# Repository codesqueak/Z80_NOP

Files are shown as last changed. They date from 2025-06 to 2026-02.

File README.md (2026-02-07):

# Z80 NOP Tester v1.2 

Z80 CPU NOP Instruction Tester

## Introduction

This board has been designed to allow a Z80 to run NOP instructions slowly enough to see address and various control lines to aid in diagnostics

In Z80 assembly, NOP (No Operation) is the opcode 0x00.

When executed, the CPU does nothing for one machine cycle and then increments the program counter (PC) to fetch the next instruction.

## What it Tests
* Clock circuit (CPU is being driven)
* Reset circuit (PC starts at 0x0000)
* Address bus (sequential counting)
* Basic instruction fetch and decode mechanism

## What You Can See
* A display of the address bus contents as it increments
* Status of RFSH, M1, MREQ and RD signals

## What You Can Measure
* Test points for clock, 0V and 5V
* Test points for s RFSH, M1, MREQ, RD IORQ, WR, HALT, BUSACK (Useful if your Z80 is mis-behaving)

# Z80 NOP HALT Tester v2.1

Z80 CPU NOP HALT Instruction Tester

## Introduction

An extended version of the board which allows the use of HALT instructions to test dynamic memory refresh operations

In Z80 assembly, HALT is the opcode 0x76.

When executed, the CPU enters HALT mode and ceases executing except for memory refresh operations

## Documentation

For full documentation, see the [NOP pdf here](Z80_NOP.pdf) and [NOP HALT pdf here](Z80_NOP_HALT.pdf)

## Release 1.2 Boards

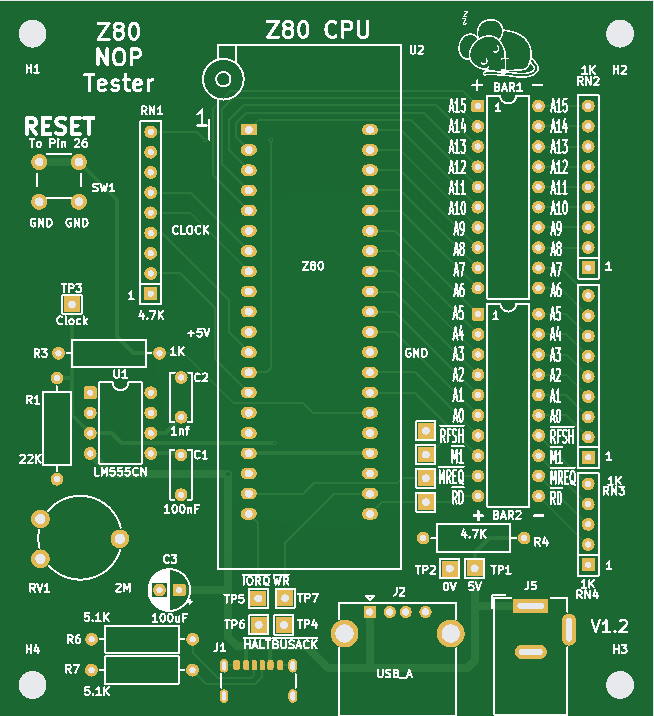
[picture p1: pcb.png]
PCB From JLCPCB


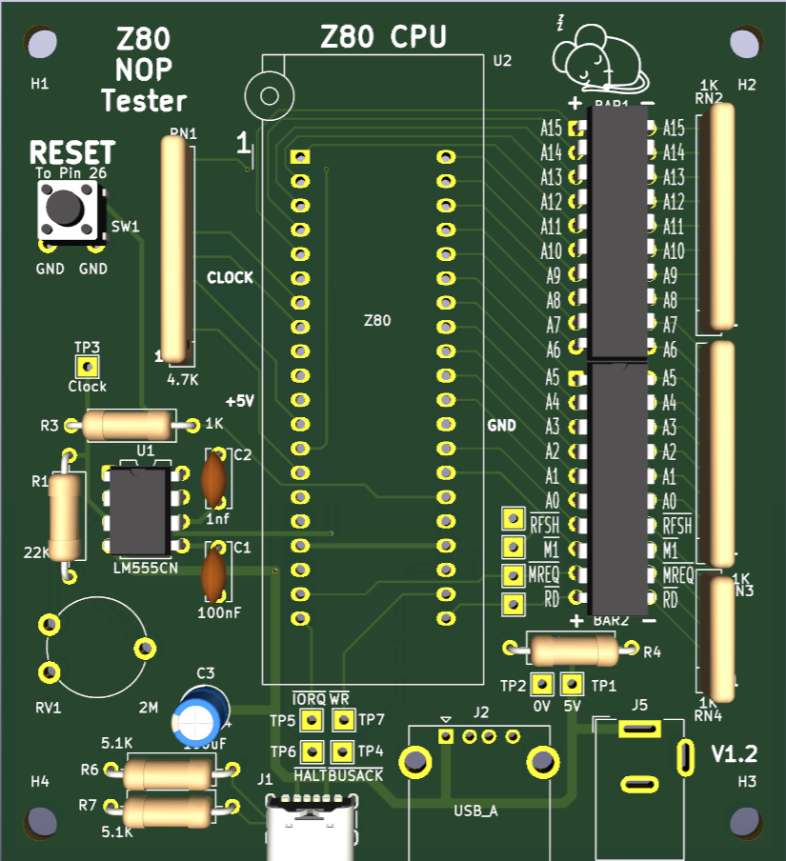
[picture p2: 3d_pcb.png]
Model


Built PCB

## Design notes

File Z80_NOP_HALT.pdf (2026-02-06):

Z80 NOP / HALT Instruction Tester

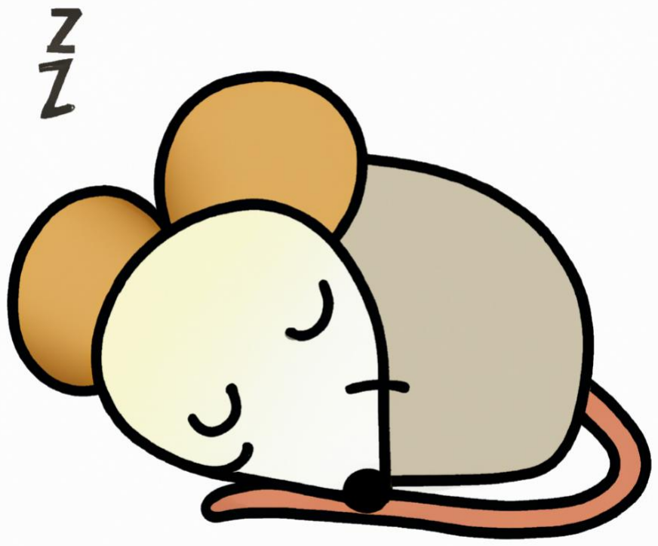
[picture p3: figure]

Issue 2.1 | Page 1 | 06-Feb-2026

## Z80 NOP / HALT Instruction Tester

Instruction Manual & Functional Description

Issue 2.1 | Page 2 | 06-Feb-2026

## Document History

Date | Reason
06_Feb-2026 | Original release

Issue 2.1 | Page 3 | 06-Feb-2026

## Contents

Issue 2.1 | Page 4 | 06-Feb-2026

## 1 Introduction

A Z80 NOP / HALT tester is a simple diagnostic tool used to check whether a Z80 microprocessor is basically functional — specifically, whether it can fetch and execute instructions from memory.

### 1.1 NOP Instruction

In Z80 assembly, NOP (No Operation) is the opcode 0x00.

When executed, the CPU does nothing for one machine cycle and then increments the program counter (PC) to fetch the next instruction.

### 1.2 HALT Instruction

In Z80 assembly, HALT is the opcode 0x76.

When executed, the CPU halts normal operation and can only be restarted by a reset, interrupt or power cycle. Despite execution halting, bus cycles to maintain memory refresh cycles continue. This is useful to check refresh operations are concurringly correctly.

### 1.3 The Tester’s Trick

The tester provides the Z80 with a "fake" memory where every address returns 0x00 (NOP) or 0x76 (HALT)

### 1.4 Expected Behavior - NOP

With only NOPs available, the Z80 should:

- Continuously fetch opcodes (all NOPs).
- Increment the PC from 0x0000 to 0xFFFF, then wrap around.
- Output the address on the address bus sequentially, one step per instruction cycle.

### 1.5 What it Tests

- Clock circuit (CPU is being driven).
- Reset circuit (PC starts at 0x0000).
- Address bus (sequential counting).
- Basic instruction fetch and decode mechanism.

### 1.6 What You Can See

- A display of the address bus contents as it increments
- Status of HALT, RFSH, M1 and MREQ signals

### 1.7 What You Can Measure

- Test points for clock, 0V and 5V
- Test points for s RFSH, M1, MREQ, RD IORQ, WR, HALT, BUSACK (Useful if your Z80 is mis-behaving)

### 1.8 Expected Behavior - HALT

With only HALTs available, the Z80 should:

- HALT LED goes blank (Active low)
- Cease incrementing the PC

Issue 2.1 | Page 5 | 06-Feb-2026
- Output the address on the address bus sequentially for refresh. only lower 7 bits (A0..A6). A7 to A15 should remain off in this mode

### 1.9 What it Tests

- Clock circuit (CPU is being driven).
- Reset circuit (CPU enters HALT mode).
- Address bus (sequential counting for refresh only).
- Basic instruction fetch and decode mechanism.

### 1.10 What You Can See

- A display of the address bus contents as it increments
- Status of HALT, RFSH, M1 and MREQ signals

### 1.11 What You Can Measure

- Test points for clock, 0V and 5V
- Test points for s RFSH, M1, MREQ, RD IORQ, WR, HALT, BUSACK (Useful if your Z80 is mis-behaving)

With this it is possible to confirm basic IC functionality while looking at expected signal quality (if you have a scope to hand)

Issue 2.1 | Page 6 | 06-Feb-2026

## 2 Components

Reference | Value | Qty | Part
BAR1 | LED_Bar_10 | 1 | OSX10201-G
BAR2 | LED_Bar_10 | 1 | OSX10201-RGG
C1 | 100nF | 1 | Ceramic
C2 | 1nf | 1 | Ceramic (*)
C3 | 100uF | 1 | Electrolytic
C4 | 10nF | 1 | Ceramic
J1 | USB_C_Receptacle_PowerOnly_6P | 1 | USB4125-GF-A
J2 | USB_A | 1 | KUSBX-AS1N
J5 | Barrel Jack | 1 | Wurth 694108301002
R1 | 22K | 1
R3 | 1K | 1
R4 | 4.7K | 1
R6, R7 | 5.1K | 2 | Optional on J1 being fitted
RN1 | 4.7K | 1 | 4116R-1-472
RN2, RN3 | 1K | 2 | 4609M-101-102LF
RN4 | 1K | 1 | 4605X-101-102LF
RV1 | 2M | 1 | PT10LV10-205A2020-S
SW1 | Switch Push | 1
SW1 | Switch Slide | 1
TP1 | 5V | 1
TP2 | 0V | 1
TP3 | Clock | 1
TP4 | BUSACK | 1
TP5 | IORQ | 1
TP6 | RD | 1
TP7 | WR | 1
TP8 | HALT | 1
TP9 | MREQ | 1
TP10 | M1 | 1
TP11 | RFSH | 1
U1 | 555 Timer | 1 | LM555CN
U2 | Z80 | 1 | Test Item

(*) Can be changed to give a different clock range. See section 5

Issue 2.1 | Page 7 | 06-Feb-2026

## 3 Construction

### 3.1 Before you start construction

Inspect the PCB for any visible signs of damage

Select your components:

- Turned pin sockets are recommended due to robustness and reliability

### 3.2 Order of construction

The recommended order of construction is:

- Resistors
- Sockets
- Resistor packs
- LED’s
- Power connectors
- Reset switch
- ZIF Socket
- Insert IC

### 3.3 Note on USB C

If the USB C connector is not to be fitted then the two 5.1K resistors (R6 & R7) are also not required.

Issue 2.1 | Page 8 | 06-Feb-2026

## 4 Functionality

### 4.1 Order of Operation

To test a CPU, the following steps are required

- Put the CPU in the ZIF socket and clamp it
- Select either NOP or HALT mode
- Apply power via one of the power inputs
- Press the reset button

### 4.2 Operation Speed

Depending on the clock speed selected A0 may appear fully lit or flicker due to the rate of change

The time taken / speed of operation is controlled by the variable resistor RV1. In standard configuration this gives an approximate clock of between 325Hz and 22KHz

It is possible to change C1 and C2 to give other ranges if required. For example, using C1 @ 47nF and C2 at 2.2nF gives an approximate clock of between 150Hz and 10KHz

The original C1, C2 values have been chosen to give reasonable time performance while making the address bus changes visible.

### 4.3 Expected Output - NOP

The LED’s representing A0 through A15 should now count in the sequence as the CPU runs through addresses 0000 to FFFF

The four LED’s representing HALT, RFSH, M1 and MREQ should all stay lit. RFSH, M1 and MREQ do change state but too quickly to be easily visible. Using a scope on their test points if recommended if exact operation needs to be observed.

### 4.4 Expected Output - HALT

The LED’s representing A0 through A6 should now count in the sequence as the CPU runs through its refresh address generation. A7 through A15 should not light.

The three LED’s representing RFSH, M1 and MREQ should all stay lit. They do change state but too quickly to be easily visible. Using a scope on their test points if recommended if exact operation needs to be observed.

The HALT LED should not be lit. This indices the CPU is in HALT mode

Issue 2.1 | Page 9 | 06-Feb-2026

Issue 2.1 | Page 10 | 06-Feb-2026

## 5 Notes on Components

All the components used have been selected at time of design to be readily available via eBay and other sources.

All components with the exception of the USB C connector are through hole so specialist tooling is not required

It is recommended that all through hole resistors are rated at 0.5W for over-rating reliability

The ZIF socket can be soldered directly to the board. You may wish to consider using a socket to mount the ZIF socket into as they can be expensive and easy to damage via soldering.

Make sure the reset button is oriented correctly before soldering

Not all 555’s seem to be created equal. I strongly recommend using an LM555CN

Th e capacitor at C2 is set to 1nF. This gives a range of approximately 325Hz to 22KHz. This may be changes as follows:

Capacitor | Approx Min | Approx Max
1nF | 325Hz | 22KHz
2.2nF | 150Hz | 10KHz
4.7nF | 75Hz | 5KHz

Issue 2.1 | Page 11 | 06-Feb-2026

## 6 Errata

None so far …

Issue 2.1 | Page 12 | 06-Feb-2026

## 7 Design Files

https://github.com/codesqueak/Z80_NOP

Issue 2.1 | Page 13 | 06-Feb-2026

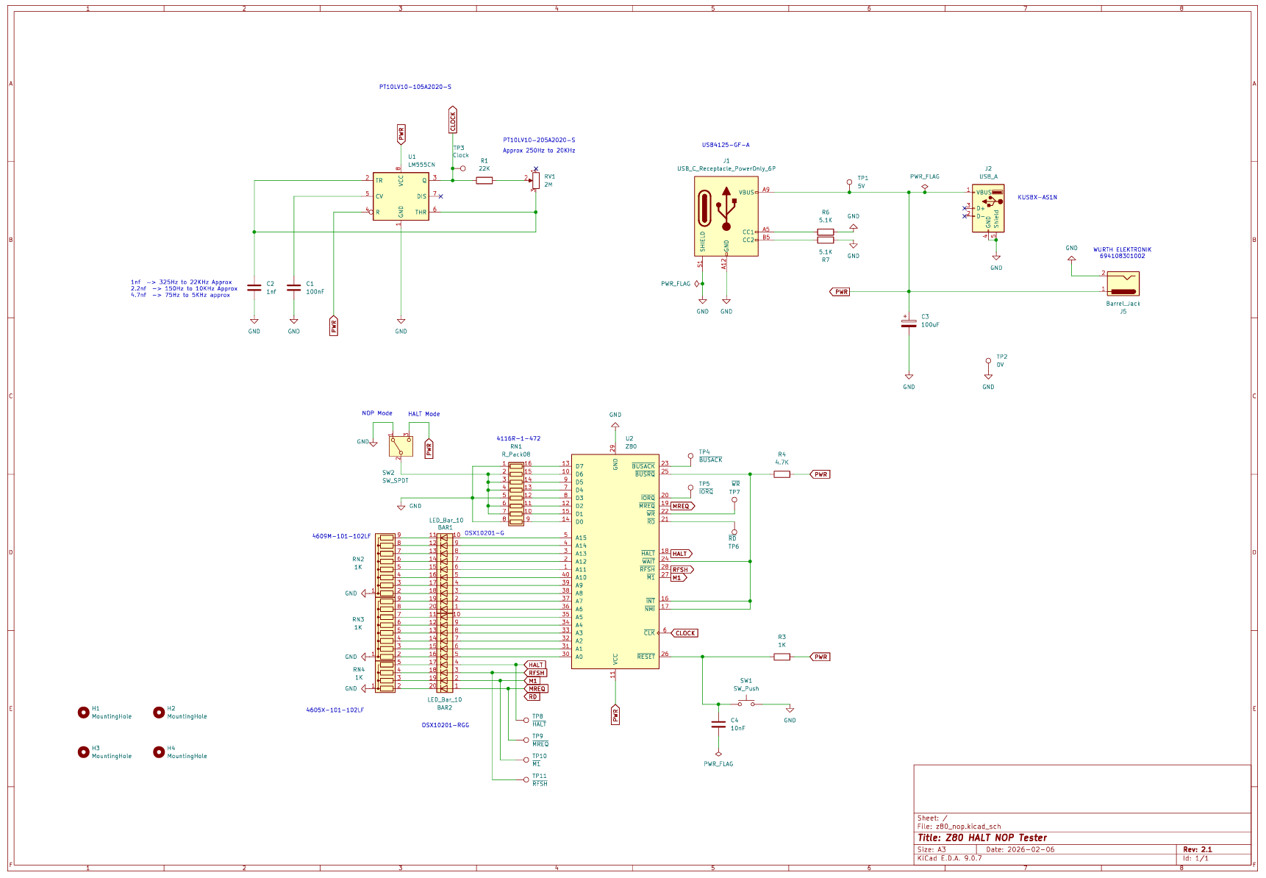
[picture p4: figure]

Issue 2.1 | Page 14 | 06-Feb-2026

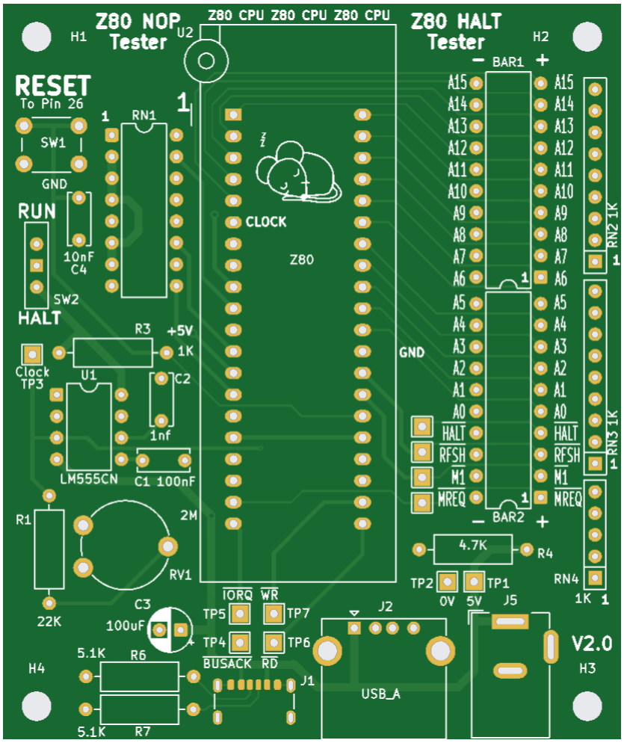
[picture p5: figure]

Issue 2.1 | Page 15 | 06-Feb-2026

## 8 Reference Images

### 8.1 PCB

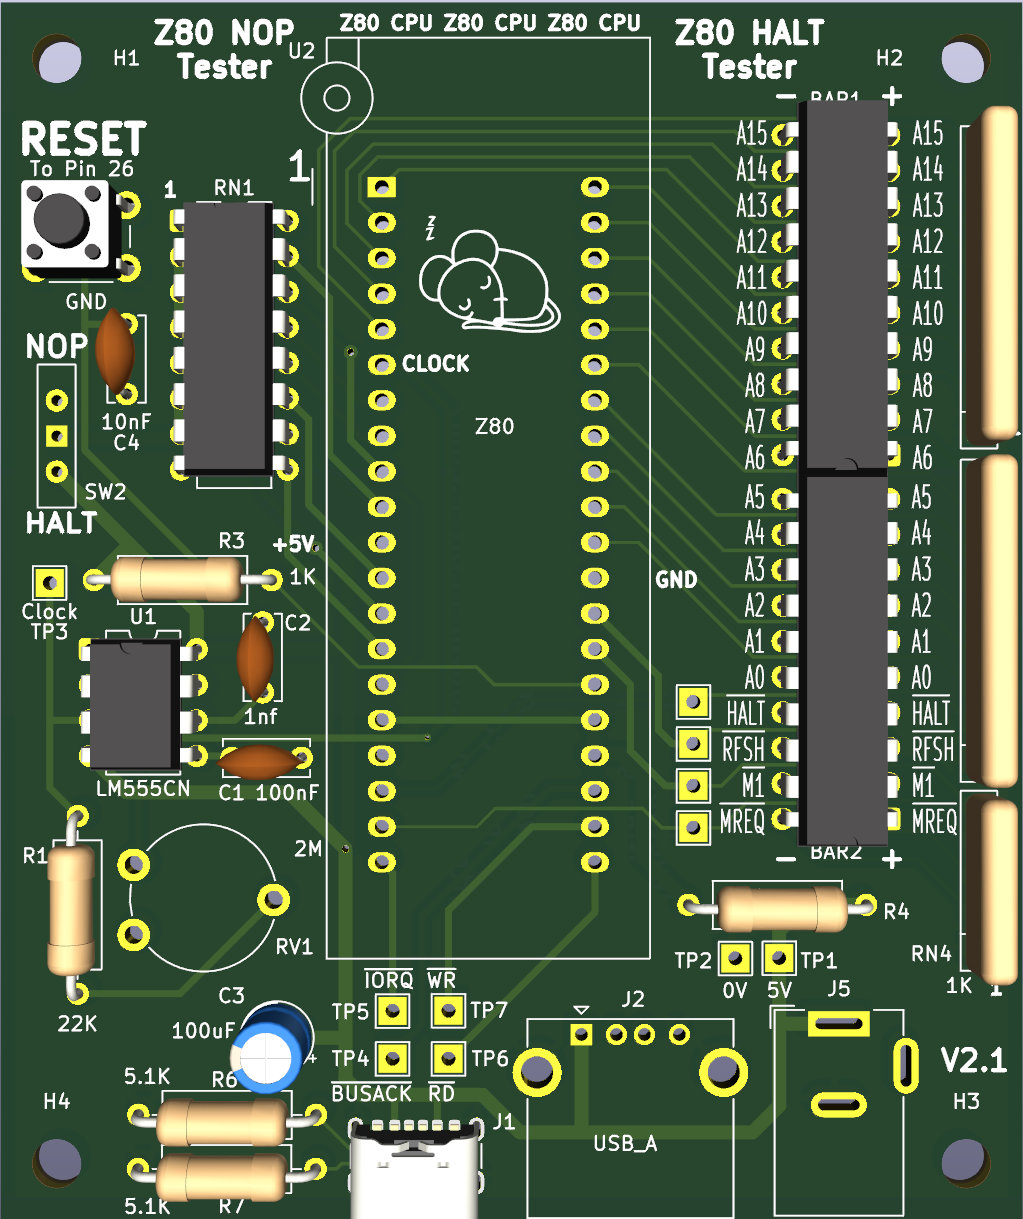
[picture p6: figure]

Issue 2.1 | Page 16 | 06-Feb-2026

### 8.2 Built

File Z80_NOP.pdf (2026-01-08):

Z80 NOP Instruction Tester


Issue 1.3 | Page 1 | 08-Jan-2026

## Z80 NOP Instruction Tester

Instruction Manual & Functional Description

Issue 1.3 | Page 2 | 08-Jan-2026

## Document History

Date | Reason
11-Aug-2025 | Original release
04-Oct-2025 | Minor corrections
08-Jan-2026 | Additional capacitor to clock speed selections

Issue 1.3 | Page 3 | 08-Jan-2026

## Contents

Issue 1.3 | Page 4 | 08-Jan-2026

## 1 Introduction

A Z80 NOP tester is a simple diagnostic tool used to check whether a Z80 microprocessor is basically functional — specifically, whether it can fetch and execute instructions from memory.

### 1.1 NOP Instruction

In Z80 assembly, NOP (No Operation) is the opcode 0x00.

When executed, the CPU does nothing for one machine cycle and then increments the program counter (PC) to fetch the next instruction.

### 1.2 The Tester’s Trick

The tester provides the Z80 with a "fake" memory where every address returns 0x00 (NOP).

### 1.3 Expected Behavior

With only NOPs available, the Z80 should:

- Continuously fetch opcodes (all NOPs).
- Increment the PC from 0x0000 to 0xFFFF, then wrap around.
- Output the address on the address bus sequentially, one step per instruction cycle.

### 1.4 What it Tests

- Clock circuit (CPU is being driven).
- Reset circuit (PC starts at 0x0000).
- Address bus (sequential counting).
- Basic instruction fetch and decode mechanism.

### 1.5 What You Can See

- A display of the address bus contents as it increments
- Status of RFSH, M1, MREQ and RD signals

### 1.6 What You Can Measure

- Test points for clock, 0V and 5V
- Test points for s RFSH, M1, MREQ, RD IORQ, WR, HALT, BUSACK (Useful if your Z80 is mis-behaving)

With this it is possible to confirm basic IC functionality while looking at expected signal quality (if you have a scope to hand)

Issue 1.3 | Page 5 | 08-Jan-2026

## 2 Components

Reference | Value | Qty | Part
BAR1,BAR2 | LED_Bar_10 | 2 | OSX10201-G
C1 | 100nF | 1 | Ceramic
C2 | 1nf | 1 | Ceramic (*)
C3 | 100uF | 1 | Electrolytic
J1 | USB_C_Receptacle_PowerOnly_6P | 1 | USB4125-GF-A
J2 | USB_A | 1 | KUSBX-AS1N
J5 | Barrel Jack | 1 | Wurth 694108301002
R1 | 22K | 1
R3 | 1K | 1
R4 | 4.7K | 1
R6, R7 | 5.1K | 2 | Optional on J1 being fitted
RN1 | 4.7K | 1 | 4609M-101-472LF
RN2, RN3 | 1K | 2 | 4609M-101-102LF
RN4 | 1K | 1 | 4605X-101-102LF
RV1 | 2M | 1 | PT10LV10-205A2020-S
SW1 | Switch Push | 1 | D6L90 F2 LFS
TP1 | 5V | 1
TP2 | 0V | 1
TP3 | Clock | 1
TP4 | BUSACK | 1
TP5 | IORQ | 1
TP6 | HALT | 1
TP7 | WR | 1
TP8 | RD | 1
TP9 | MREQ | 1
TP10 | M1 | 1
TP11 | RFSH | 1
U1 | 555 Timer | 1 | LM555CN
U2 | Z80 | 1 | Test Item

(*) Can be changed to give a different clock range. See section 5

Issue 1.3 | Page 6 | 08-Jan-2026

## 3 Construction

### 3.1 Before you start construction

Inspect the PCB for any visible signs of damage

Select your components:

- Turned pin sockets are recommended due to robustness and reliability

### 3.2 Order of construction

The recommended order of construction is:

- Resistors
- Sockets
- Resistor packs
- LED’s
- Power connectors
- Reset switch
- ZIF Socket
- Insert IC

### 3.3 Note on USB C

If the USB C connector is not to be fitted then the two 5.1K resistors (R6 & R7) are also not required.

Issue 1.3 | Page 7 | 08-Jan-2026

## 4 Functionality

### 4.1 Order of Operation

To test a CPU, the following steps are required

- Put the CPU in the ZIF socket and clamp it
- Apply power via one of the power inputs
- Press the reset button

### 4.2 Expected Output

The LED’s representing A0 through A15 should now count in the sequence as the CPU runs through addresses 0000 to FFFF

Depending on the clock speed selected A0 may appear fully lit or flicker due to the rate of change

The time taken / speed of operation is controlled by the variable resistor RV1. In standard configuration this gives an approximate clock of between 325Hz and 22KHz

It is possible to change C1 and C2 to give other ranges if required. For example, using C1 @ 47nF and C2 at 2.2nF gives an approximate clock of between 150Hz and 10KHz

The original C1, C2 values have been chosen to give reasonable time performance while making the address bus changes visible.

The four LED’s representing RFSH, M1, MREQ and RD should all stay lit. They do change state but too quickly to be easily visible. Using a scope on their test points if recommended if exact operation needs to be observed.

Issue 1.3 | Page 8 | 08-Jan-2026

## 5 Notes on Components

All the components used have been selected at time of design to be readily available via eBay and other sources.

All components with the exception of the USB C connector are through hole so specialist tooling is not required

It is recommended that all through hole resistors are rated at 0.5W for over-rating reliability

The ZIF socket can be soldered directly to the board. You may wish to consider using a socket to mount the ZIF socket into as they can be expensive and easy to damage via soldering.

Make sure the reset button is oriented correctly before soldering

Not all 555’s seem to be created equal. I strongly recommend using an LM555CN

Th e capacitor at C2 is set to 1nF. This gives a range of approximately 325Hz to 22KHz. This may be changes as follows:

Capacitor | Approx Min | Approx Max
1nF | 325Hz | 22KHz
2.2nF | 150Hz | 10KHz
4.7nF | 75Hz | 5KHz

Issue 1.3 | Page 9 | 08-Jan-2026

## 6 Errata

None so far …

Issue 1.3 | Page 10 | 08-Jan-2026

## 7 Design Files

https://github.com/codesqueak/Z80_NOP

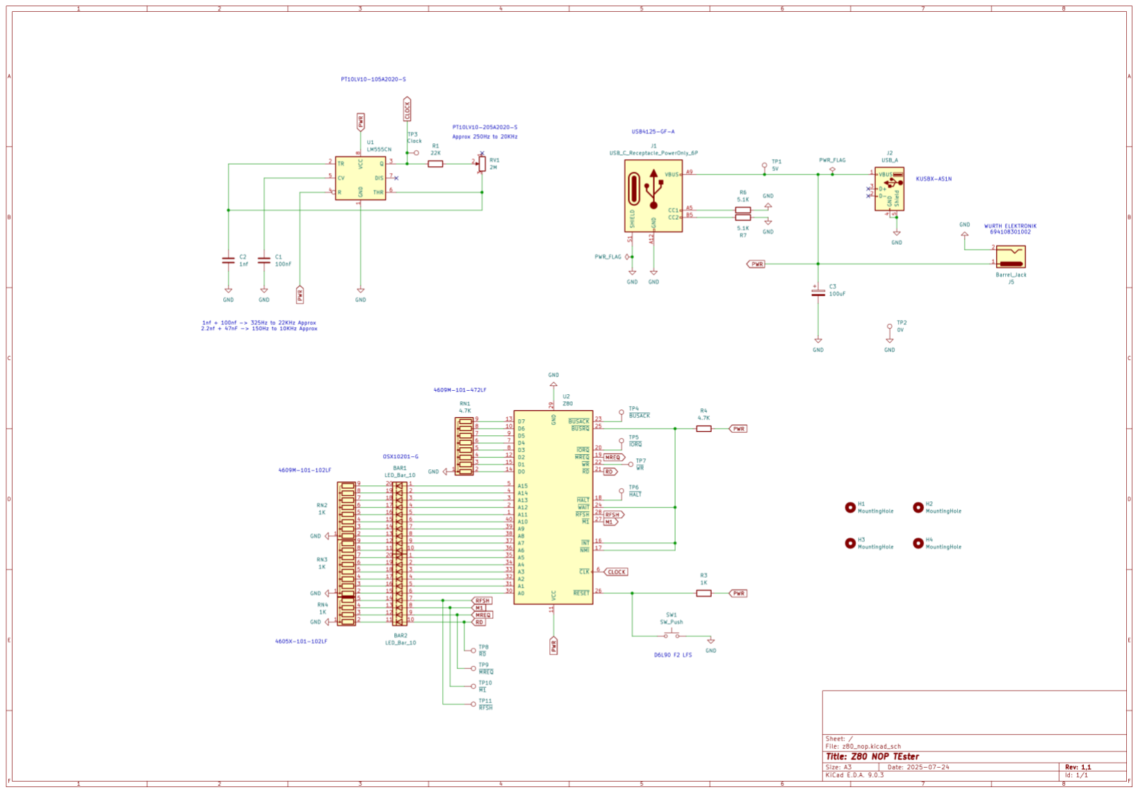
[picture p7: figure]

Issue 1.3 | Page 11 | 08-Jan-2026

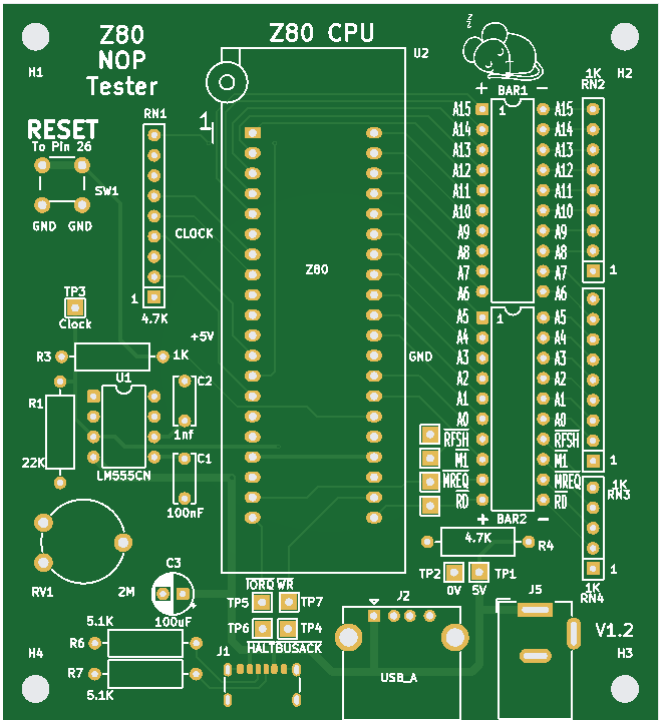
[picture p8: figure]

Issue 1.3 | Page 12 | 08-Jan-2026

## 8 Reference Images

### 8.1 PCB

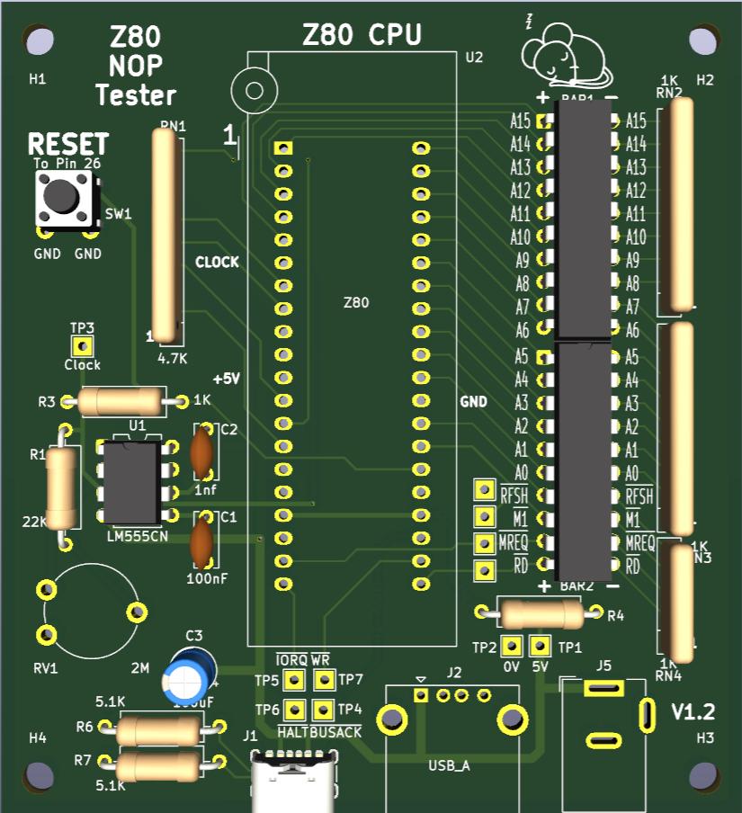
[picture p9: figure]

Issue 1.3 | Page 13 | 08-Jan-2026

### 8.2 Built

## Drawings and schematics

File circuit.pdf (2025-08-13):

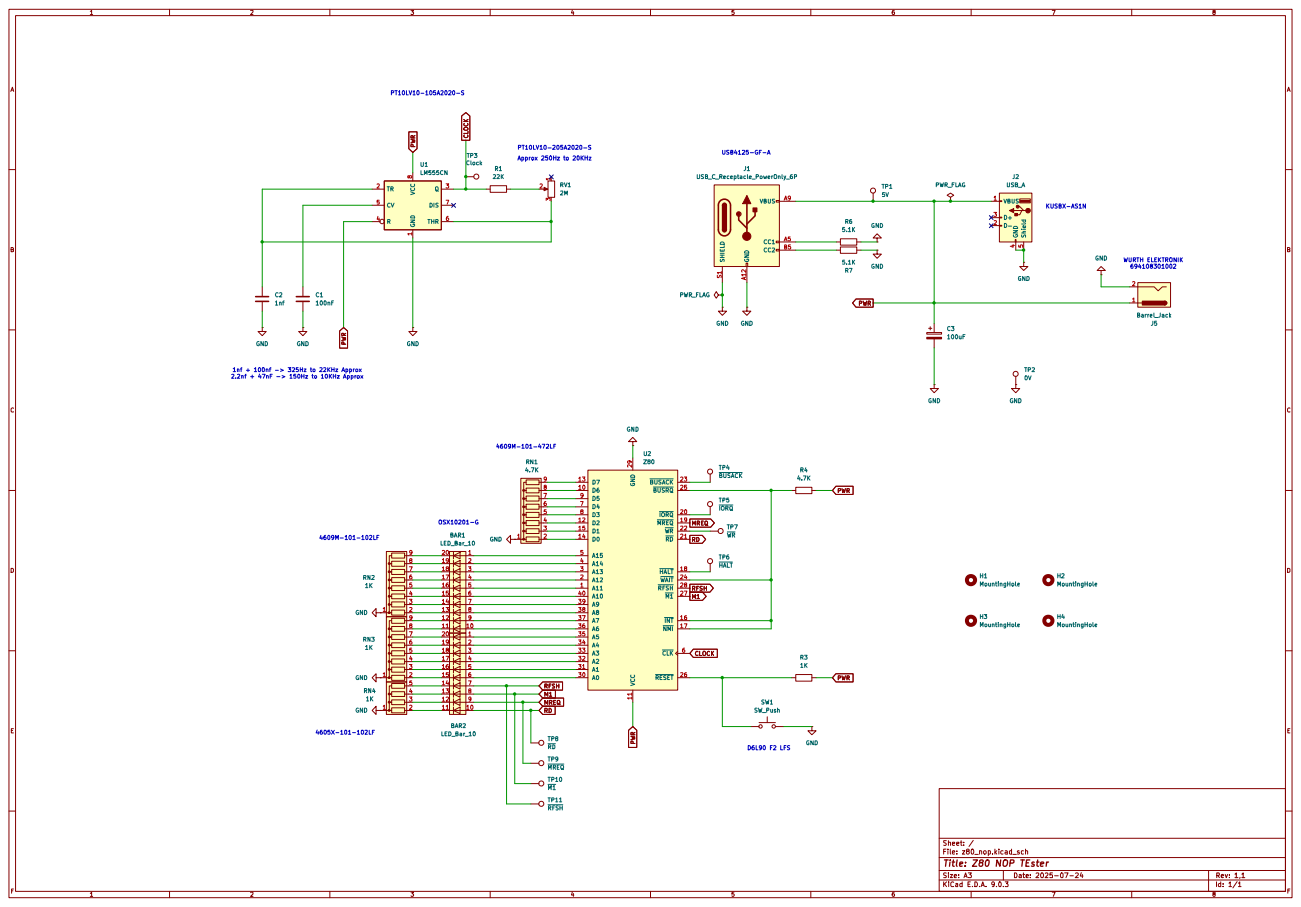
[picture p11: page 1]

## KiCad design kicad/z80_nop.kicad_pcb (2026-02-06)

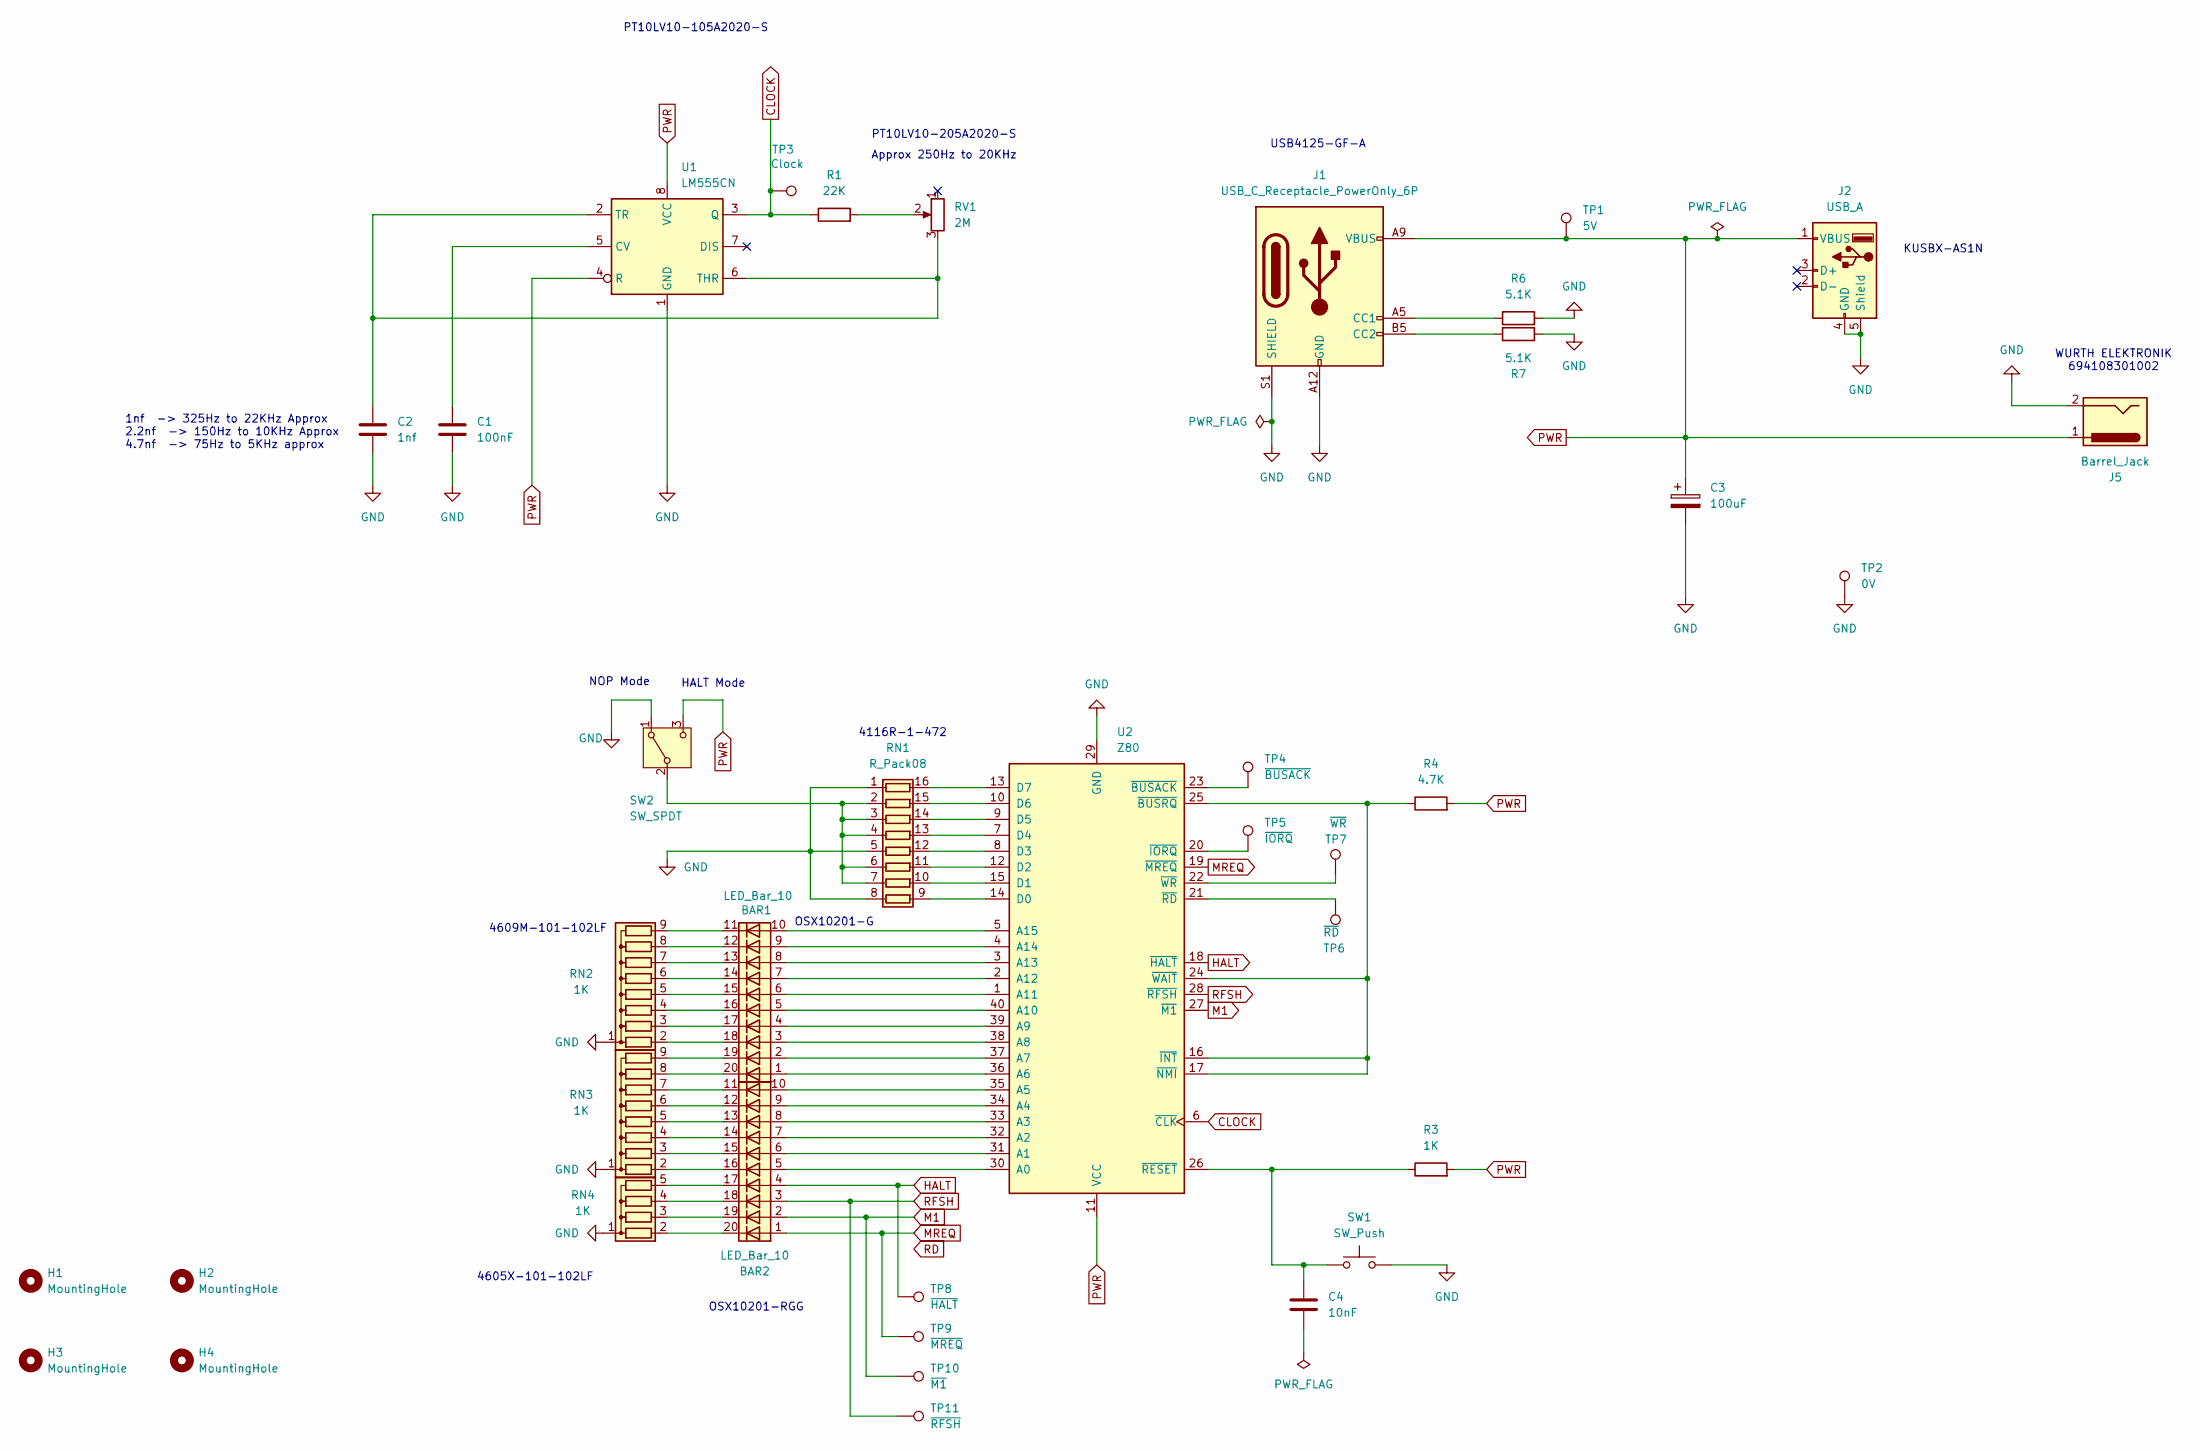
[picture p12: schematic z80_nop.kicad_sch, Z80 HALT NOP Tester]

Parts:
BAR1, BAR2: LED_Bar_10; DIP-20_W7.62mm
C1: 100nF; C_Disc_D6.0mm_W2.5mm_P5.00mm
C2: 1nf; C_Disc_D6.0mm_W2.5mm_P5.00mm
C3: 100uF; CP_Radial_D5.0mm_P2.50mm
C4: 10nF; C_Disc_D6.0mm_W2.5mm_P5.00mm
H1, H2, H3, H4: MountingHole; MountingHole_3.5mm
J1: USB_C_Receptacle_PowerOnly_6P; USB_C_Receptacle_GCT_USB4125-xx-x-0190_6P_TopMnt_Horizontal
J2: USB_A; USB_A_Kycon_KUSBX-AS1N-B_Horizontal
J5: Barrel_Jack; BarrelJack_Wuerth_6941xx301002
R1: 22K; R_Axial_DIN0309_L9.0mm_D3.2mm_P12.70mm_Horizontal
R3: 1K; R_Axial_DIN0309_L9.0mm_D3.2mm_P12.70mm_Horizontal
R4: 4.7K; R_Axial_DIN0309_L9.0mm_D3.2mm_P12.70mm_Horizontal
R6, R7: 5.1K; R_Axial_DIN0309_L9.0mm_D3.2mm_P12.70mm_Horizontal
RN1: R_Pack08; DIP-16_W7.62mm
RN2, RN3: 1K; R_Array_SIP9
RN4: 1K; R_Array_SIP5
RV1: 2M; Potentiometer_Piher_PT-10-V10_Vertical
SW1: SW_Push; SW_PUSH_6mm_H5mm
SW2: SW_SPDT; SW_Slide-03_Pin-2-Common_10x2.5x6.4_P2.54mm
TP1: 5V; TestPoint_THTPad_2.0x2.0mm_Drill1.0mm
TP2: 0V; TestPoint_THTPad_2.0x2.0mm_Drill1.0mm
TP3: Clock; TestPoint_THTPad_2.0x2.0mm_Drill1.0mm
TP4: ~{BUSACK}; TestPoint_THTPad_2.0x2.0mm_Drill1.0mm
TP5: ~{IORQ}; TestPoint_THTPad_2.0x2.0mm_Drill1.0mm
TP6: ~{RD}; TestPoint_THTPad_2.0x2.0mm_Drill1.0mm
TP7: ~{WR}; TestPoint_THTPad_2.0x2.0mm_Drill1.0mm
TP8: ~{HALT}; TestPoint_THTPad_2.0x2.0mm_Drill1.0mm
TP9: ~{MREQ}; TestPoint_THTPad_2.0x2.0mm_Drill1.0mm
TP10: ~{M1}; TestPoint_THTPad_2.0x2.0mm_Drill1.0mm
TP11: ~{RFSH}; TestPoint_THTPad_2.0x2.0mm_Drill1.0mm
U1: LM555CN; DIP-8_W7.62mm
U2: Z80; DIP_Socket-40_W11.9_W12.7_W15.24_W17.78_W18.5_ZIF

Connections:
CLOCK: R1.1, TP3.1, U1.3 (Q), U2.6 (~CLK)
GND: C1.2, C2.2, C3.2, J1.A12 (GND), J1.B12 (GND), J1.S1 (SHIELD), J2.4 (GND), J2.5 (Shield), J5.2, R6.2, R7.2, RN1.1 (R1.1), RN1.5 (R5.1), RN1.8 (R8.1), RN2.1 (common), RN3.1 (common), RN4.1 (common), SW1.2, SW2.1 (A), TP2.1, U1.1 (GND), U2.29 (GND)
HALT: BAR2.4 (A), TP8.1, U2.18 (~HALT)
M1: BAR2.2 (A), TP10.1, U2.27 (~M1)
MREQ: BAR2.1 (A), TP9.1, U2.19 (~MREQ)
unnamed: J1.A5 (CC1), R6.1
unnamed: J1.B5 (CC2), R7.1
unnamed: R1.2, RV1.2
unnamed: RN1.16 (R1.2), U2.13 (D7)
unnamed: RN1.2 (R2.1), RN1.3 (R3.1), RN1.4 (R4.1), RN1.6 (R6.1), RN1.7 (R7.1), SW2.2 (B)
unnamed: RN1.15 (R2.2), U2.10 (D6)
unnamed: RN1.14 (R3.2), U2.9 (D5)
unnamed: RN1.13 (R4.2), U2.7 (D4)
unnamed: RN1.12 (R5.2), U2.8 (D3)
unnamed: RN1.11 (R6.2), U2.12 (D2)
unnamed: RN1.10 (R7.2), U2.15 (D1)
unnamed: RN1.9 (R8.2), U2.14 (D0)
unnamed: BAR1.18 (K), RN2.2 (R1)
unnamed: BAR1.17 (K), RN2.3 (R2)
unnamed: BAR1.16 (K), RN2.4 (R3)
unnamed: BAR1.15 (K), RN2.5 (R4)
unnamed: BAR1.14 (K), RN2.6 (R5)
unnamed: BAR1.13 (K), RN2.7 (R6)
unnamed: BAR1.12 (K), RN2.8 (R7)
unnamed: BAR1.11 (K), RN2.9 (R8)
unnamed: BAR2.16 (K), RN3.2 (R1)
unnamed: BAR2.15 (K), RN3.3 (R2)
unnamed: BAR2.14 (K), RN3.4 (R3)
unnamed: BAR2.13 (K), RN3.5 (R4)
unnamed: BAR2.12 (K), RN3.6 (R5)
unnamed: BAR2.11 (K), RN3.7 (R6)
unnamed: BAR1.20 (K), RN3.8 (R7)
unnamed: BAR1.19 (K), RN3.9 (R8)
unnamed: BAR2.20 (K), RN4.2 (R1)
unnamed: BAR2.19 (K), RN4.3 (R2)
unnamed: BAR2.18 (K), RN4.4 (R3)
unnamed: BAR2.17 (K), RN4.5 (R4)
unnamed: C1.1, U1.5 (CV)
unnamed: C2.1, RV1.3, U1.2 (TR), U1.6 (THR)
unnamed: BAR2.5 (A), U2.30 (A0)
unnamed: BAR2.6 (A), U2.31 (A1)
unnamed: BAR2.7 (A), U2.32 (A2)
unnamed: BAR2.8 (A), U2.33 (A3)
unnamed: BAR2.9 (A), U2.34 (A4)
unnamed: BAR2.10 (A), U2.35 (A5)
unnamed: BAR1.1 (A), U2.36 (A6)
unnamed: BAR1.2 (A), U2.37 (A7)
unnamed: BAR1.3 (A), U2.38 (A8)
unnamed: BAR1.4 (A), U2.39 (A9)
unnamed: BAR1.5 (A), U2.40 (A10)
unnamed: BAR1.6 (A), U2.1 (A11)
unnamed: BAR1.7 (A), U2.2 (A12)
unnamed: BAR1.8 (A), U2.3 (A13)
unnamed: BAR1.9 (A), U2.4 (A14)
unnamed: BAR1.10 (A), U2.5 (A15)
unnamed: TP4.1, U2.23 (~BUSACK)
unnamed: R4.1, U2.16 (~INT), U2.17 (~NMI), U2.24 (~WAIT), U2.25 (~BUSRQ)
unnamed: TP5.1, U2.20 (~IORQ)
unnamed: TP6.1, U2.21 (~RD)
unnamed: C4.1, R3.1, SW1.1, U2.26 (~RESET)
unnamed: TP7.1, U2.22 (~WR)
PWR: C3.1, J1.A9 (VBUS), J1.B9 (VBUS), J2.1 (VBUS), J5.1, R3.2, R4.2, SW2.3 (C), TP1.1, U1.4 (R), U1.8 (VCC), U2.11 (VCC)
RFSH: BAR2.3 (A), TP11.1, U2.28 (~RFSH)

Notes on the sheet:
4116R-1-472
USB4125-GF-A
4605X-101-102LF
OSX10201-G
OSX10201-RGG
Approx 250Hz to 20KHz
KUSBX-AS1N
NOP Mode
4609M-101-102LF
HALT Mode
PT10LV10-205A2020-S
WURTH ELEKTRONIK 694108301002
PT10LV10-105A2020-S
1nf -> 325Hz to 22KHz Approx 2.2nf -> 150Hz to 10KHz Approx 4.7nf -> 75Hz to 5KHz approx

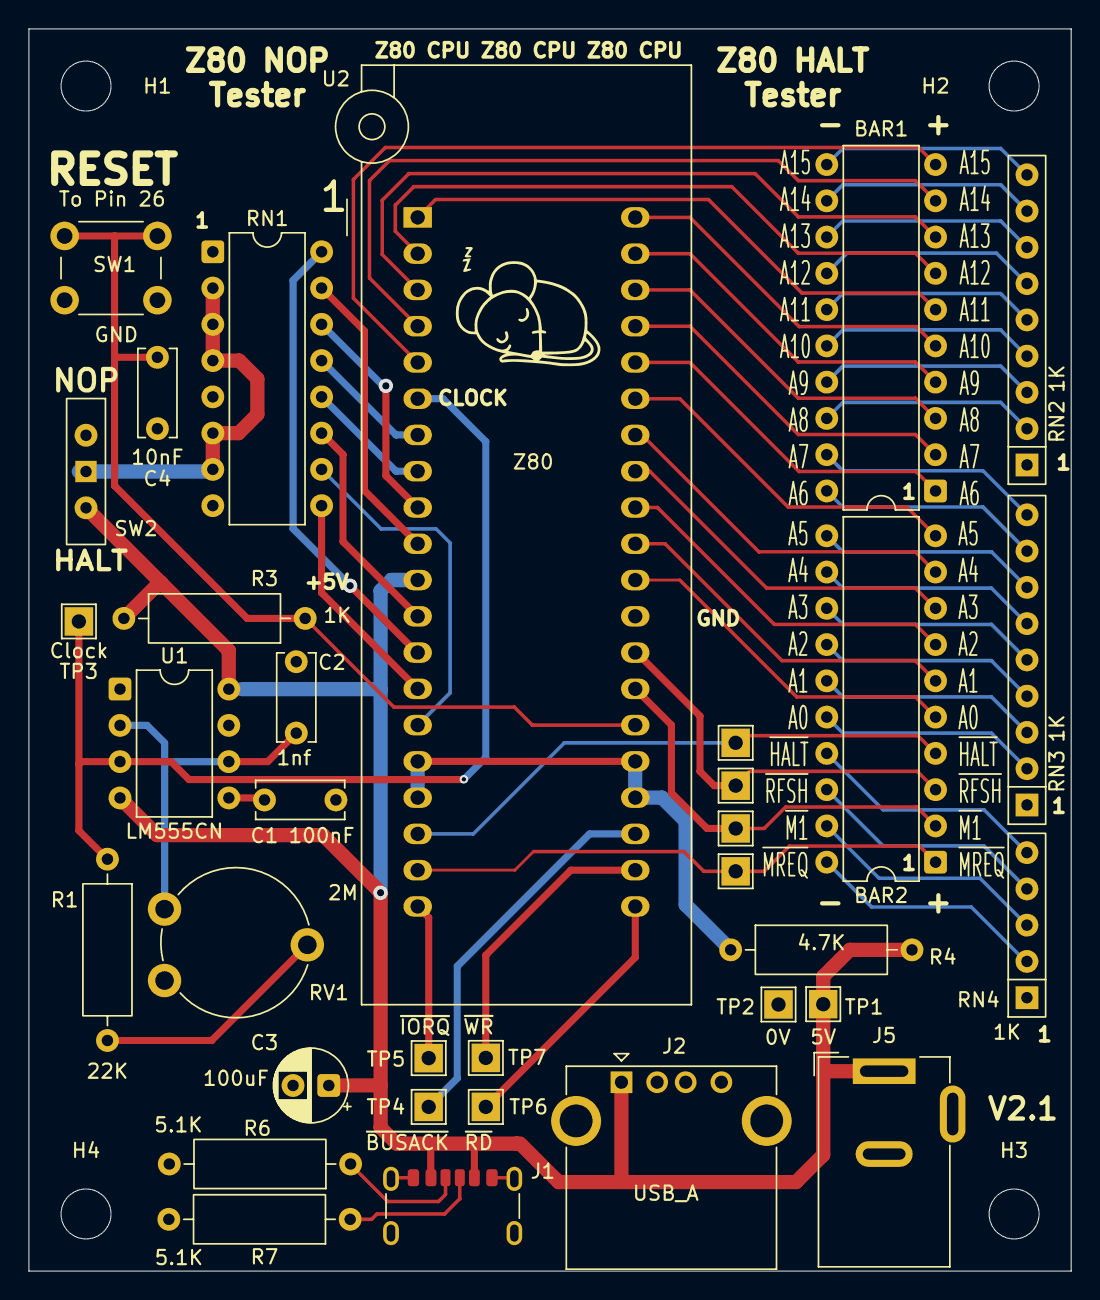
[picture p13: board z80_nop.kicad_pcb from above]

Board: 2 copper layers, 73.0 x 87.0 mm, 40 parts (1 on the bottom side), 63 nets.

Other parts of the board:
G001, G002: LOGO; sleepymouse_very_very_small

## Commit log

2025-06-28 Initial upload
    [z80_nop.kicad_pcb, z80_nop.kicad_sch]
2025-06-28 Update PCB
2025-08-10 Minor tweaks
    [z80_nop.kicad_pcb, z80_nop.kicad_sch]
2026-01-08 Update docs
    [z80_nop.kicad_sch]
2026-02-06 Add HALT mode
    [z80_nop.kicad_pcb, z80_nop.kicad_sch]
2026-02-06 Update docs, add gerbers
